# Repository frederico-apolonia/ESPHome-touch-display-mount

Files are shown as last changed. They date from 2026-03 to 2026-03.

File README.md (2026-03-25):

# ESP32 Cheap Yellow Display (ESP32-2432S028) Home Assistant Touch Panel – LVGL UI + 3D Printed Desk / Under-Desk Tilt Mount





ESPHome powered Home Assistant control panel using the popular Cheap Yellow Display (ESP32-2432S028).

A 3D-printable enclosure with adjustable tilt for an ESP32 2.8" ILI9341 touchscreen, powered by ESPHome + LVGL and integrated with Home Assistant.  
Includes ready-to-flash YAML configs for the ESP32-2432S028 (Cheap Yellow Display) and a standalone ILI9341 + external ESP32 wiring variant.

Three mounting options are supported:

• Desk Mount – for tabletop installation  
• Under-Desk Mount – for installation underneath a desk or shelf  
• Wall Mount – for wall installation (CYD version only)

The enclosure can therefore be used as a compact Home Assistant control panel for desks, walls, or mounted underneath desk or furniture.

------------------------------------------------------------------------

The ESP32-2432S028 Cheap Yellow Display is transformed into a tiltable Home Assistant control panel powered by ESPHome and LVGL.

The goal of this project is to create a clean, wall- or desk-mounted smart control panel that integrates seamlessly with Home Assistant.  
It features a modern LVGL-based UI, real-time state synchronization, and optional direct Home Assistant service calls.

The enclosure is designed for:

- Clean cable routing  
- Adjustable viewing angle (±35° tilt)  
- Minimal footprint  
- Professional, integrated appearance  

Two hardware variants are supported:

- ✅ **ESP32-2432S028 (Cheap Yellow Display / CYD)**
- ✅ **Standalone ILI9341 + External ESP32 wiring variant**

The ESP32-2432S028 integrates the ESP32, ILI9341 display, touchscreen controller, and backlight circuitry on a single board.  
It is commonly known as the **Cheap Yellow Display (CYD)** in the maker community and is the easiest option for this project.










## Demo
https://github.com/user-attachments/assets/68709d8e-21ec-4851-bf73-70f583027390

Note: The video quality looks worse than in real life because the display refresh rate interferes with the camera frame rate when filming the screen. In reality the UI looks much smoother and cleaner.

---

# 🆕 Architecture Overview (LVGL-Based UI)

This project uses ESPHome LVGL instead of a classic display lambda approach.

### Core Concepts

- UI rendered fully using LVGL widgets
- 4 configurable touch buttons
- Real-time state mirroring from Home Assistant
- Central `ui_refresh` script keeps UI synchronized
- Optional direct Home Assistant service calls
- Action sensor for automation-based control

### Two Control Modes

#### 1️⃣ Direct Mode (Default – Plug & Play)

If `DIRECT_ACTIONS` is set to `"true"` (default):

- Touch publishes an action string
- AND directly calls a Home Assistant service  
  (default: `light.toggle`)

No Home Assistant automations required.

#### 2️⃣ Automation Mode

If `DIRECT_ACTIONS` is set to `"false"`:

- Touch ONLY publishes an action string
- You implement behavior in Home Assistant automations

Trigger example:
```
Entity: sensor.smartdisplay_action
To: btn1_press
```

### Overlay Control Layer

The UI contains a secondary overlay layer used for interactive controls.

When a tile is long-pressed:

1. The overlay opens
2. The control type is determined (brightness / percentage)
3. Slider interaction updates Home Assistant
4. Closing the overlay returns to the tile grid

This keeps the tile UI clean while still allowing detailed control.

# ⚙️ Requirements

- Home Assistant installed
- ESPHome Add-on installed
- ESPHome 2026.2+
- Home Assistant 2026.2+
- Basic ESPHome knowledge
- 3D printer access (optional)

---

# 🧪 Tested With

This project was tested using:

- **ESPHome 2026.2+**
- **Home Assistant 2026.2+**
- ESP32-2432S028 (Cheap Yellow Display / CYD)
- ILI9341 + XPT2046 standalone wiring variant

# ⚠️ IMPORTANT -- Enable "Actions" in Home Assistant

Because this project uses:

```
homeassistant.action → light.toggle
```

You must allow the ESPHome device to perform Home Assistant service calls.

### How to enable:

1. Open Home Assistant  
2. Go to **Settings**  
3. Click **Devices & Services**  
4. Open the **ESPHome integration**  
5. Select your device  
6. Enable:

> "Allow the device to perform Home Assistant actions"

Without this setting, direct control will not work.

---

# ✨ Features

- LVGL-based UI (lockscreen or tile layout depending on configuration)
- 2×3 configurable tile layout (home-like UI)
- Long-press control overlay for brightness / fan speed
- Real-time state synchronization with Home Assistant
- Optional direct Home Assistant service calls
- Automation-based mode supported
- Adjustable 3D-printed enclosure
- Desk mount or under-desk mount options
- Hidden cable routing
- Works with CYD or external ESP32 wiring

------------------------------------------------------------------------

# 📦 Hardware

## Option A -- ESP32-2432S028 (Cheap Yellow Display Board -- Recommended)

| Part | Price | Comment |
|---|---|---|
| ESP32-2432S028			 | 15$ | 2.8" ILI9341 with integrated ESP |
| 2x M4 3.5x16 screw (flathead)| 0.10$ | Screws to connect the mount case with the base  |

Advantages:

-   Single USB cable
-   Clean installation
-   No manual wiring
-   Widely available under the name "Cheap Yellow Display"

| ESP32-2432S028 | PIN | Comment |
|---|---|---|
| LCD | | |
| clk_pin | GPIO14 | SPI LCD Clock |
| mosi_pin | GPIO13 | SPI LCD MOSI (sometimes also labeled as SDI) |
| miso_pin 	 		 | GPIO12 | SPI LCD MISO (sometimes also labeled as SDO	 |
| cs_pin | GPIO15 | Display CS |
| dc_pin | GPIO2 | Display DC |
| Touchscreen | | |
| clk_pin | GPIO25 | SPI Touchscreen Clock |
| mosi_pin | GPIO32 | SPI Touchscreen MOSI (sometimes also labeled as DIN) |
| miso_pin | GPIO39 | SPI Touchscreen MISO (sometimes also labeled as DO)  |
| cs_pin | GPIO33 | Touchscreen CS |
| interrupt_pin | GPIO36 | Touchscreen Interrupt |
| LED | | |
| ledc | GPIO21 | Backlight LED display |
| ledc | GPIO4 | Onboard LED (not used for this project) |

------------------------------------------------------------------------

### Power connection (CYD)

For the mount enclosure the side USB connector of the CYD is **not used**.

Instead the included power cable can be used.  
The **red and black wires provide 5V and GND** and can easily be connected to an old USB-A cable.

Typical setup:

1. Cut an old USB cable
2. Connect **5V (red)** and **GND (black)** to the CYD power cable
3. Route the cable through the enclosure
4. Solder or use small wire connectors

This keeps the enclosure compact and avoids having a visible or protruding USB connector on the side.

If the USB port was used directly, the enclosure would need to be wider or the connector would remain visible.

⚠️ Important: The CYD often has multiple identical JST connectors, but they do not share the same pinout. Make sure to use the connector labeled VIN / 5V. Other connectors may be labeled 3.3V, and connecting 5V there can damage the board.



## Option B -- Standalone Display + ESP32

| Part | Price | Comment |
|---|---|---|
| 2.8" ILI9341 			 | 8$ | 2.8" ILI9341 |
| ESP32 Wroom 32D 		 | 8$ | or some ESP32 |
| 2x M4 3.5x16 screw (flathead)| 0.10$ | Screws to connect the mount case with the base  |

Requires manual wiring according to the YAML pin configuration.

Use the wiring table below, which shows how to put everything together.

| ILI9341 | PIN  ESP32 | Comment |
|---|---|---|
| GND | GND | Ground |
| VCC | 3.3V | Power |
| LCD | | |
| SCK | GPIO18 | SPI LCD Clock |
| SDI (MOSI) | GPIO23 | SPI LCD MOSI (sometimes also labeled as SDI) |
| SDO (MISO) 	 	 | GPIO19 | SPI LCD MISO (sometimes also labeled as SDO	 |
| CS | GPIO27 | Display CS |
| D/C | GPIO26 | Display DC |
| RESET | GPIO16 | Display Reset |
| Touchscreen | | |
| T_CLK | GPIO25 | SPI Touchscreen Clock |
| T_DO | GPIO35 | SPI Touchscreen MISO (sometimes also labeled as DO) |
| T_DIN | GPIO32 | SPI Touchscreen MOSI (sometimes also labeled as DIN)  |
| T_CS | GPIO33 | Touchscreen CS |
| T_IRQ | GPIO34 | Touchscreen Interrupt |
| LED | | |
| ledc | GPIO4 | Backlight LED display |

------------------------------------------------------------------------

# 🚀 Installation

## 1. Install ESPHome (macOS with Homebrew)

```bash
brew install esphome
```

Verify the installation:

```bash
esphome version
```

## 2. Create `secrets.yaml`

The YAML configs reference credentials via `!secret`. Create the file at:

```
esphome/cyd-2432s028/secrets.yaml
```

with the following entries (fill in your own values):

```yaml
api_encryption_key: ""   # 32-byte base64 key — generate with: esphome generate-encryption-key
ota_password: ""         # any password you choose for OTA updates
wifi_ssid: ""            # your Wi-Fi network name
wifi_password: ""        # your Wi-Fi password
```

> `secrets.yaml` is listed in `.gitignore` and will never be committed.

## 3. Compile and flash the CYD-2432S028

Connect the board via USB, then run from the repo root:

```bash
# home-like tile UI
esphome run esphome/cyd-2432s028/home-like.yml

# or the lockscreen buttons UI
esphome run esphome/cyd-2432s028/buttons.yaml
```

`esphome run` compiles the firmware and flashes it over USB in one step.
For subsequent updates you can flash over Wi-Fi (OTA) — ESPHome will detect the device automatically.

---

Available YAML variants (pick **one UI** for your **hardware**):

### Cheap Yellow Display (ESP32-2432S028 / CYD)
- `esphome/cyd-2432s028/buttons.yaml` – lockscreen with 4 round buttons (good for quick toggles)
- `esphome/cyd-2432s028/home-like.yml` – 2x3 “tiles” UI (wallpaper + tiles)

### External display wiring (any ESP32 + ILI9341 + XPT2046)
- `esphome/ili9341-external-esp32/buttons.yaml` – lockscreen with 4 round buttons
- `esphome/ili9341-external-esp32/home-like.yml` – 2x3 “tiles” UI (wallpaper + tiles)

> Tip: Both `home-like.yml` files share a single background image located at `esphome/images/smartdisplay_background.png`.
> Because the YAML files live in subfolders, reference it as `../images/smartdisplay_background.png` in the `image:` section.

------------------------------------------------------------------------

### Assets (required for the UI)
- **Material Design Icons font**: place `materialdesignicons-webfont.ttf` at `esphome/fonts/materialdesignicons-webfont.ttf`.
  - You can get it from the MaterialDesignIcons project (TTF release) or your local install.
  - If you change icons in the YAML, ensure the glyph list contains them.
- **Background image (home-like UI)**:
  - Default file: `esphome/images/smartdisplay_background.png` (included in this repo).
  - In `home-like.yml`, reference it as `/images/smartdisplay_background.png` (relative to the YAML file).
# ⚙️ UI mapping (USER CONFIG)

Your config choice defines the UI style:

## `buttons.yaml` (lockscreen like buttons)
- Buttons: BTN1..BTN4
- Action strings: `btn1_press` .. `btn4_press`
- Default direct action (if `DIRECT_ACTIONS: "true"`): `light.toggle` on `BTN*_ENTITY`



## `home-like.yml` (tiles)
- Tiles: TILE1..TILE6
- Action strings: `tile1_press` .. `tile6_press`
- Each tile can optionally call a Home Assistant service directly (toggle/scene/script/fan preset/light brightness).
- Per-tile OFF label is configurable via `TILE*_LABEL_OFF` (e.g. "Off" / "Aus").

### Long-Press Overlay

Tiles can open a control overlay when long-pressed.

Depending on the tile configuration, the overlay provides:

| Tile Type | Overlay Control |
|---|---|
| light | Brightness slider |
| fan | Speed / percentage slider |
| custom | Optional custom behavior |

The overlay allows quick adjustments without leaving the tile UI.




------------------------------------------------------------------------

# 🧠 System Flow

### Direct Mode

1. Button pressed  
2. Action string published  
3. Home Assistant service called  
4. Entity state updated  
5. Mirrored back into ESPHome  
6. UI refreshed  

### Automation Mode

1. Button pressed  
2. Action string published  
3. Home Assistant automation triggers  
4. Automation controls device  
5. State mirrored back  

------------------------------------------------------------------------

# 🔧 Customization

For most setups, you only need to edit the **USER CONFIG / substitutions** section in the YAML.

You can also:

-   Add more buttons / pages
-   Change service calls (the default is `light.toggle`)
-   Modify fonts and icon glyphs
-   Adjust colors / theme
-   Date localization can be adjusted in the ui_refresh script (days[] / months[] arrays).
-   Adjust transforms for your panel

If touch alignment is wrong, ensure `display.transform` and `touchscreen.transform`
are **identical** (they must always match).

------------------------------------------------------------------------
# Troubleshooting

### Corrupted / garbled display output

If the display shows **corrupted graphics, horizontal lines, or random pixels**, the most common cause is a **different display controller on your Cheap Yellow Display**.

Most CYD boards use **ILI9341**, but some variants ship with **ST7789** or **ILI9342**.  
If the driver in ESPHome does not match the controller, the display output may look broken.

Try changing the display model in the YAML:

```yaml
display:
  - platform: ili9xxx
    model: ILI9341
```

Alternative models that may work depending on your board:

```yaml
model: ST7789V
```

or

```yaml
model: ILI9342
```

Flashing with a different model is usually the fastest way to identify the correct controller.

---

### Display rotated / mirrored

If the UI appears **rotated, mirrored, or upside down**, adjust the `transform`
settings.

Both the **display** and the **touchscreen** configuration must match,
otherwise touch input will be misaligned.

Common parameters:

```yaml
transform:
  swap_xy: true
  mirror_x: true
  mirror_y: true
```
Depending on the board variant, you may need to experiment with these values until the orientation matches your screen.
Make sure the display.transform and touchscreen.transform settings use the same orientation.

------------------------------------------------------------------------

# 🖨 3D Printing

See the `/3d_print` folder for STL files and Fusion 360 source files.

Three mount options are available:

• **Desk Mount** – for tabletop installation  
• **Under-Desk Mount** – for installation underneath a desk or shelf  
• **Wall Mount** – for wall installation (CYD version)

Desk mount and Under-Desk mount use the same enclosure parts and adjustable tilt mechanism.  
Print the main enclosure parts and choose one mount type depending on your setup.

Designed for:

- Desk mounting
- Under-desk mounting
- Wall mounting
- Adjustable viewing angle
- Hidden cable routing

------------------------------------------------------------------------

# ⚠️ Disclaimer

This is a hobby project and considered work-in-progress.

Feel free to fork, remix and improve it.

# Other





# More projects
Looking for more cool projects using this display? Check out the [LoctekMotion Touch Display GitHub repository](https://github.com/3DJupp/LoctekMotion-TouchDisplay)! This awesome project takes the same 2.8" ILI9341 touchscreen setup and repurposes it—not for lights, but for controlling a height-adjustable Flexispot desk with ease. If you're into smart home automation and custom builds, it's definitely worth a look!

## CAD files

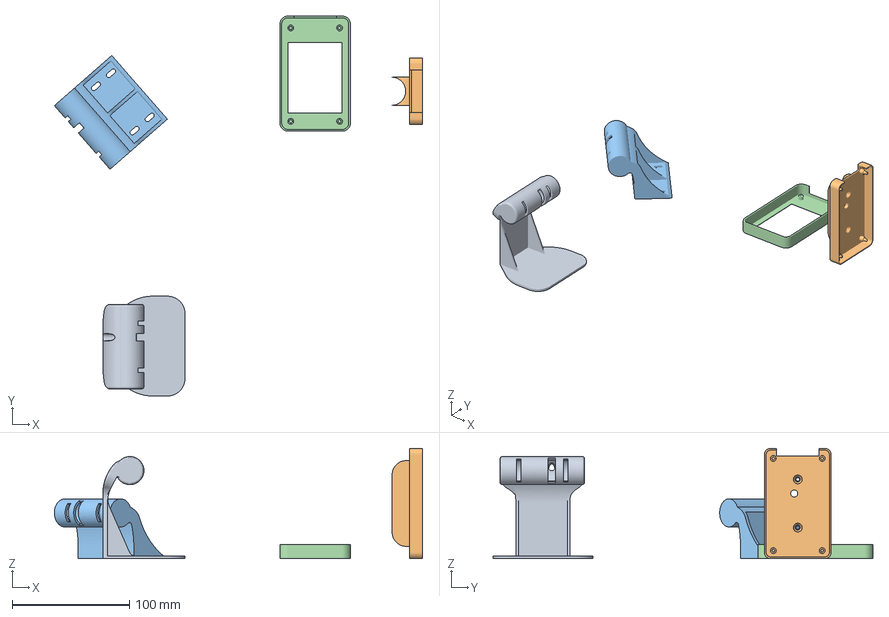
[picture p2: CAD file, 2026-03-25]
3d_print/CYD Mount.3mf
313.6 x 323.5 x 94.0 mm
desk-mount.stl
inner-body-adjusted.stl
under-desk-mount.stl
cover_fixed.stl

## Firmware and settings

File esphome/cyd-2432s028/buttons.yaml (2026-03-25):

############################################################
# SmartDisplay (Cheap Yellow Display / CYD) – ESPHome + LVGL lockscreen UI
#
# Target hardware
# - Cheap Yellow Display (CYD)
#   (ESP32 + ILI9341 320x240 display + XPT2046 touchscreen)
#
# Purpose
# - LVGL renders a simple “lockscreen” UI: time/date + 4 toggle buttons.
#
# Touch input → Home Assistant
# - Every touch publishes an “action” string via a text_sensor:
#     sensor.smartdisplay_action = "btn1_press" / "btn2_press" / "btn3_press" / "btn4_press"
# - The sensor is auto-reset to "" after each press so repeated presses trigger reliably.
#
# Two supported control modes (choose what fits your setup)
# 1) Direct control (DEFAULT, simplest)
#    - DIRECT_ACTIONS: "true" (default)
#    - Each touch will:
#        • publish the action string AND
#        • directly call a Home Assistant service
#          (default: light.toggle on BTN*_ENTITY)
#    - Use this if you simply want to toggle lights without creating automations.
#
# 2) Automation-only control (custom logic)
#    - DIRECT_ACTIONS: "false"
#    - Each touch will ONLY publish the action string.
#    - You implement the behavior in Home Assistant automations using:
#        Trigger → State → sensor.smartdisplay_action → To: btn1_press (etc.)
#
# If you do NOT want to toggle lights
# - Either change the homeassistant.action blocks to a different service
#   (e.g. switch.toggle, script.turn_on, scene.turn_on, ...)
# - Or set DIRECT_ACTIONS to "false" and handle everything via HA automations.
#
# UI updates
# - On boot, every minute, and whenever the configured HA entities change
#   (mirrored into ESPHome to keep LVGL button states in sync).
#
# What you must adapt before flashing
# 1) Secrets: api.encryption.key, ota.password, WiFi credentials (prefer secrets.yaml)
# 2) BTN*_ENTITY: Home Assistant entity IDs you want to control/mirror
# 3) Touch calibration + transform:
#    - calibration is panel-specific
#    - touchscreen.transform MUST match display.transform exactly
#
# Home Assistant note
# - In the ESPHome device settings, enable:
#   “Allow the device to perform Home Assistant actions”
#   Otherwise homeassistant.action calls are blocked.
############################################################

# ==========================================================
# USER CONFIG (edit this section to match your HA setup)
#
# - DIRECT_ACTIONS:
#     "true"  -> touch publishes action + calls HA service (light.toggle by default)
#     "false" -> touch only publishes action (all logic handled in HA)
#
# - BTN*_ENTITY:
#     The Home Assistant entity to control and mirror for the button state.
#     Must exist in Home Assistant.
#
# - BTN*_LABEL / BTN*_ICON:
#     Only affects what is shown on the display.
# ==========================================================
substitutions:
  # Enable/disable direct Home Assistant service calls on touch.
  # - "true"  -> touching a button also calls light.toggle (plug & play)
  # - "false" -> touching a button ONLY publishes the action text_sensor
  DIRECT_ACTIONS: "true"

  # Button 1
  BTN1_ENTITY: "light.reading_light"
  BTN1_LABEL: "Reading"
  BTN1_ICON: "\U000F095F"

  # Button 2
  BTN2_ENTITY: "light.ceiling_light"
  BTN2_LABEL: "Ceiling"
  BTN2_ICON: "\U000F0769"

  # Button 3
  BTN3_ENTITY: "cover.office_blinds_cover"
  BTN3_LABEL: "Blinds"
  BTN3_ICON: "\U000F00AC"

  # Button 4
  BTN4_ENTITY: "light.ambient_light"
  BTN4_LABEL: "Ambient"
  BTN4_ICON: "\U000F1051"

  # Temperature and weather — shown below the time display
  BTN_TEMP_ENTITY: "sensor.openweathermap_temperature"
  BTN_WEATHER_ENTITY: "sensor.openweathermap_weather"
# ==========================================================

esphome:
  name: smartdisplay
  friendly_name: SmartDisplay
  on_boot:
    priority: 600
    then:
      - script.execute: ui_refresh

esp32:
  board: esp32dev
  framework:
    type: arduino

logger:

api:
  encryption:
    key: !secret api_encryption_key

ota:
  - platform: esphome
    password: !secret ota_password

wifi:
  ssid: !secret wifi_ssid
  password: !secret wifi_password

captive_portal:

globals:
  - id: active_entity
    type: std::string
    restore_value: no

  - id: active_control_kind
    type: std::string
    restore_value: no

  - id: active_value_suffix
    type: std::string
    restore_value: no

# Use Home Assistant time so the display always matches your HA timezone.
time:
  - platform: homeassistant
    id: homeassistant_time
    on_time:
      - seconds: 0
        minutes: /1
        then:
          - script.execute: ui_refresh
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

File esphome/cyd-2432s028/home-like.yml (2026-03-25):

############################################################
# SmartDisplay – iOS Home app–inspired Tiles UI
# Target device: ESP32-2432S028 / Cheap Yellow Display (CYD)
# Resolution: 320x240
#
# Target hardware
# - Cheap Yellow Display (ESP32-2432S028 or compatible)
# - Built-in ILI9341 320x240 display
# - Built-in XPT2046 touchscreen
#
# What this config does
# - Renders a wallpaper background + a 2x3 grid of “tiles” (LVGL).
# - Each tile shows: icon (MDI font), title, and a value line.
# - Tile taps publish a short-lived text_sensor event (smartdisplay_action)
#   so you can build Home Assistant automations on top.
# - Optional: the device can also call Home Assistant services directly
#   (toggle lights/switches/fans, activate scenes/scripts, set fan preset,
#   set light brightness, set fan percentage).
#
# The layout is inspired by common modern smart home UIs.
#
# How to customize
# 1) Edit the TILE1..TILE6 blocks below.
# 2) If you change icons, ensure those glyphs are included in the MDI font glyph list.
# 3) Provide your own background image at: images/home-background.png
#
# Tile configuration model
# - TILE*_TYPE defines the entity kind: light | fan | switch | scene | script
# - TILE*_TAP_ACTION defines what happens on short tap:
#   auto | toggle | activate | fan_toggle_preset | custom
# - TILE*_LONGPRESS defines what happens on long press:
#   auto | none | brightness | percentage
# - TILE*_VALUE_MODE defines how the value line is rendered:
#   auto | brightness | percentage | preset | text
#
# Notes
# - DIRECT_ACTIONS="true" enables direct HA service calls from the device.
#   If "false", only the smartdisplay_action event is emitted.
# - In auto mode, values and long-press behavior are derived from TILE*_TYPE:
#   light -> brightness, fan -> percentage/preset, scene/script -> text
#
# What you must adapt before flashing
# 1) Secrets: api.encryption.key, ota.password, WiFi credentials (prefer secrets.yaml)
# 2) Pins, touch calibration and transform if your CYD variant differs
# 3) TILE*_ENTITY / TILE*_STATE_ENTITY: Home Assistant entity IDs you want to control/mirror
# 4) Touch calibration + transform:
#    - calibration is device-specific
#    - touchscreen.transform MUST match display.transform exactly
############################################################

substitutions:

  DIRECT_ACTIONS: "true"                           # true = call Home Assistant services directly, false = only emit action events
  ROOM_NAME: "Office"                              # room name shown in the top-left header
  TIME_24H: "true"                                 # true = 24h format, false = 12h format

  ## DIM settings
  AUTO_DIM: "true"                                 # true = enable auto dimming
  AUTO_DIM_TIMEOUT: "10"                           # seconds after last touch
  MAX_BRIGHTNESS: "100"                            # backlight brightness in percent
  DIM_BRIGHTNESS: "40"                             # dimmed backlight brightness in percent
  NIGHT_MODE: "true"                               # true = use separate dim level at night
  NIGHT_START_HOUR: "22"                           # 0-23
  NIGHT_END_HOUR: "7"                              # 0-23
  NIGHT_DIM_BRIGHTNESS: "1"                        # backlight brightness in percent at night

  # ============================================================
  # Header info — temperature and weather shown below the room name
  # These are separate from the tile entities so swapping tile
  # assignments doesn't break the header display.
  # ============================================================
  HEADER_TEMP_ENTITY: "sensor.openweathermap_temperature"
  HEADER_WEATHER_ENTITY: "sensor.openweathermap_weather"


  # ============================================================
  # TILE 1 — Ambient Light
  # ============================================================

  # --- basic settings ---
  TILE1_ENTITY: "light.office_ambient_light"       # main Home Assistant entity for this tile
  TILE1_STATE_ENTITY: "light.office_ambient_light" # entity used for active/inactive state styling
  TILE1_TITLE: "Ambient Light"                     # tile title shown in the UI
  TILE1_ICON: "\U000F0913"                         # Material Design Icons glyph (mdi:ceiling-light)
  TILE1_TYPE: "light"                              # tile type: light | fan | switch | scene | script
  TILE1_TAP_ACTION: "auto"                         # tap action: auto | toggle | activate | fan_toggle_preset | custom
  TILE1_LONGPRESS: "auto"                          # long press: auto | none | brightness | percentage
  TILE1_VALUE_MODE: "auto"                         # value mode: auto | brightness | percentage | preset | text
  TILE1_LABEL_OFF: "Off"                           # text shown when entity is off
  TILE1_LABEL_ON: "On"                             # text shown for text-mode tiles when entity is on
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

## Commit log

2026-03-25 feat(cyd-2432s028): rework CYD UI with 3-button layout, sliders, display fix
    - buttons.yaml: consolidate to 3 buttons (Reading, Blinds, Ambient) evenly
    spaced; remove unused Ceiling button
    - buttons.yaml: add long-press brightness/position slider overlay for all 3
    buttons with overlay-visible guard on on_click to prevent toggle firing
    on slider release
    - buttons.yaml: add temperature + weather info label below the clock
    - buttons.yaml: fix display orientation (mirror_x/mirror_y) and touchscreen
    transform to match
    - buttons.yaml: fix cover service to cover.set_cover_position
    - home-like.yml: fix TILE4_LONGPRESS "none" → "percentage" so blinds slider
    opens on long press
    - home-like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
    [buttons.yaml, home-like.yml]
2026-03-25 missing files
    [CYD Mount.3mf]
